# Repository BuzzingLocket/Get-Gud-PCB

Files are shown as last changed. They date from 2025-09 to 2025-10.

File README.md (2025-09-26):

# Get-Gud-PCB
Getting good at PCB
Objectives: Design a PCB with an RP2040 which includes ICs to read 9-axis of sensor data (yaw, pitch, roll, acceleration, gyro, etc)m barometric pressure and temperature.

Design requirements:
- USB-C must be included. Pay attention to VBUS as that’s your power input
- RP2040
- 9-axis measurement
- Pressure sensing
- Temperature sensing
- LCSC/JLC part # included for all symbols used (i.e C2040)
- Bonus points for readable schematics and compact layout!!!!

Using a ICM 20948 IC for 9-axis detection

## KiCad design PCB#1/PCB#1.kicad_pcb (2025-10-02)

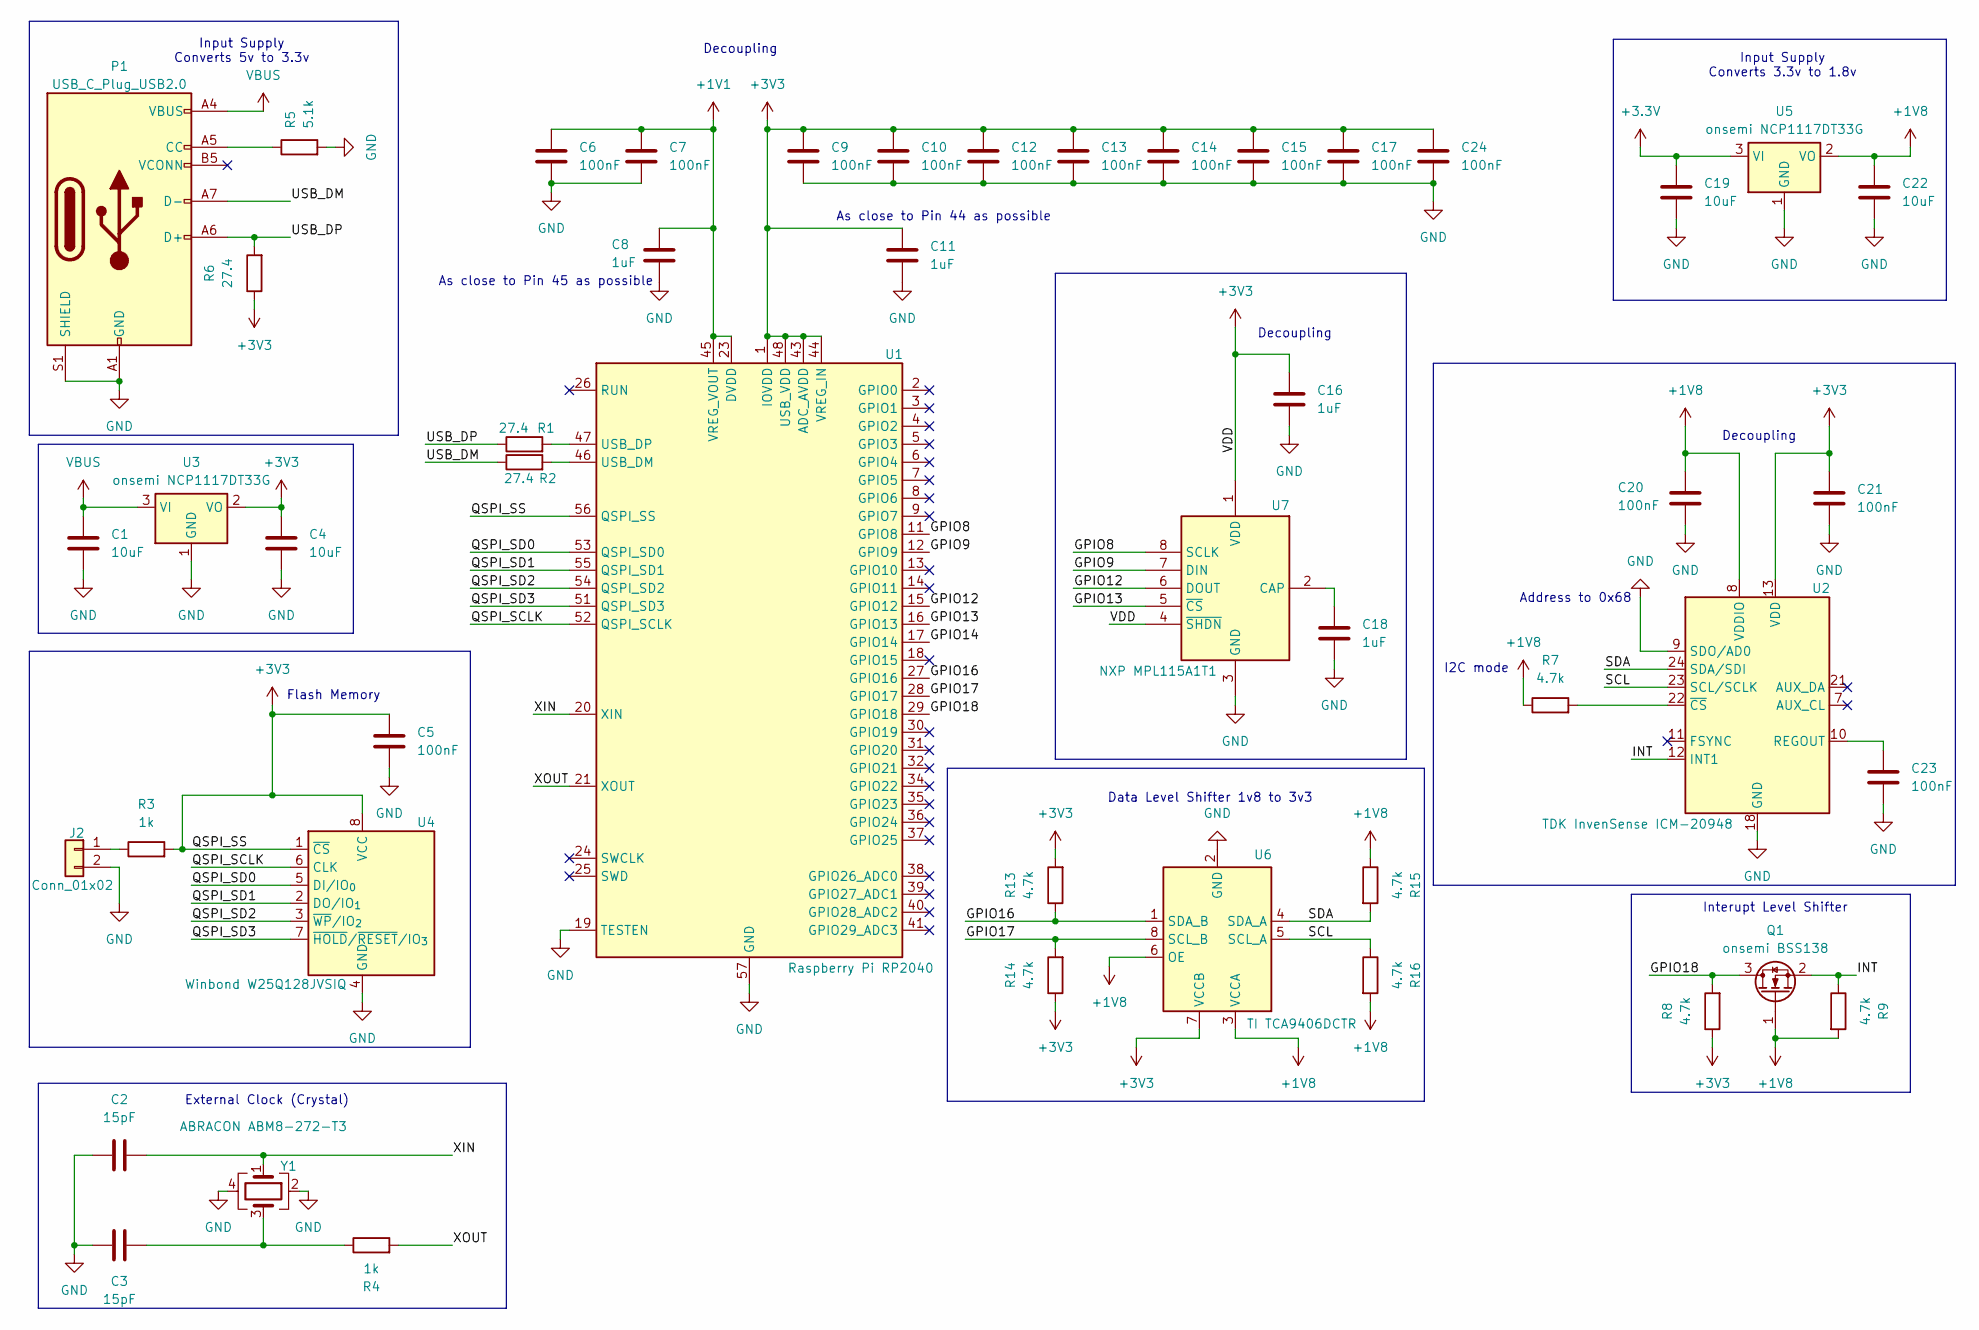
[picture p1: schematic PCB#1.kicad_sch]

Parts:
C1, C4, C19, C22: 10uF; C_0603_1608Metric
C2, C3: 15pF; C_0603_1608Metric
C5, C6, C7, C9, C10, C12, C13, C14, C15, C17, C20, C21, C23, C24: 100nF; C_0603_1608Metric
C8, C11, C16, C18: 1uF; C_0603_1608Metric
J2: Conn_01x02; PinHeader_1x02_P2.54mm_Vertical
P1: USB_C_Plug_USB2.0; USB_C_Receptacle_HRO_TYPE-C-31-M-12
Q1: onsemi BSS138; SOT-23
R1, R2, R6: 27.4; R_0603_1608Metric
R3, R4: 1k; R_0603_1608Metric
R5: 5.1k; R_0603_1608Metric
R7, R8, R9, R13, R14, R15, R16: 4.7k; R_0603_1608Metric
U1: Raspberry Pi RP2040; QFN-56-1EP_7x7mm_P0.4mm_EP3.2x3.2mm
U2: TDK InvenSense ICM-20948; InvenSense_QFN-24_3x3mm_P0.4mm
U3, U5: onsemi NCP1117DT33G; SOT-223-3_TabPin2
U4: Winbond W25Q128JVSIQ; SOIC-8_5.3x5.3mm_P1.27mm
U6: TI TCA9406DCTR; VSSOP-8_3x3mm_P0.65mm
U7: NXP MPL115A1T1; NXP_LGA-8_3x5mm_P1.25mm_H1.2mm
Y1: ABRACON ABM8-272-T3; Crystal_SMD_Abracon_ABM8G-4Pin_3.2x2.5mm

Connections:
+1V1: C6.1, C7.1, C8.1, U1.23 (DVDD), U1.45 (VREG_VOUT), U1.50 (DVDD)
+1V8: C20.1, C22.1, Q1.1 (G), R7.1, R9.2, R15.1, R16.2, U2.8 (VDDIO), U5.2 (VO), U6.3 (VCCA), U6.6 (OE)
+3.3V: C19.1, U5.3 (VI)
+3V3: C4.1, C5.1, C9.1, C10.1, C11.1, C12.1, C13.1, C14.1, C15.1, C16.1, C17.1, C21.1, C24.1, R3.2, R6.1, R8.1, R13.2, R14.1, U1.1 (IOVDD), U1.10 (IOVDD), U1.22 (IOVDD), U1.33 (IOVDD), U1.42 (IOVDD), U1.43 (ADC_AVDD), U1.44 (VREG_IN), U1.48 (USB_VDD), U1.49 (IOVDD), U1.56 (QSPI_SS), U2.13 (VDD), U3.2 (VO), U4.1 (~CS), U4.8 (VCC), U6.7 (VCCB), U7.1 (VDD), U7.4 (~SHDN)
/GPIO8: U1.11 (GPIO8), U7.8 (SCLK)
/GPIO9: U1.12 (GPIO9), U7.7 (DIN)
/GPIO12: U1.15 (GPIO12), U7.6 (DOUT)
/GPIO13: U1.16 (GPIO13), U7.5 (~CS)
/GPIO14: U1.17 (GPIO14)
/GPIO16: R13.1, U1.27 (GPIO16), U6.1 (SDA_B)
/GPIO17: R14.2, U1.28 (GPIO17), U6.8 (SCL_B)
/GPIO18: Q1.3 (D), R8.2, U1.29 (GPIO18)
/INT: Q1.2 (S), R9.1, U2.12 (INT1)
/QSPI_SCLK: U1.52 (QSPI_SCLK), U4.6 (CLK)
/QSPI_SD0: U1.53 (QSPI_SD0), U4.5 (DI/IO_{0})
/QSPI_SD1: U1.55 (QSPI_SD1), U4.2 (DO/IO_{1})
/QSPI_SD2: U1.54 (QSPI_SD2), U4.3 (~WP/IO_{2})
/QSPI_SD3: U1.51 (QSPI_SD3), U4.7 (~HOLD/~RESET/IO_{3})
/SCL: R16.1, U2.23 (SCL/SCLK), U6.5 (SCL_A)
/SDA: R15.2, U2.24 (SDA/SDI), U6.4 (SDA_A)
/USB_DM: P1.A7 (D-), R2.1
/USB_DP: P1.A6 (D+), R1.1, R6.2
/XIN: C2.1, U1.20 (XIN), Y1.1
/XOUT: R4.2, U1.21 (XOUT)
GND: C1.2, C2.2, C3.2, C4.2, C5.2, C6.2, C7.2, C8.2, C9.2, C10.2, C11.2, C12.2, C13.2, C14.2, C15.2, C16.2, C17.2, C18.2, C19.2, C20.2, C21.2, C22.2, C23.2, C24.2, J2.2, P1.A1 (GND), P1.A12 (GND), P1.B1 (GND), P1.B12 (GND), P1.S1 (SHIELD), R5.2, U1.19 (TESTEN), U1.57 (GND), U2.9 (SDO/AD0), U2.18 (GND), U2.20 (GND), U3.1 (GND), U4.4 (GND), U5.1 (GND), U6.2 (GND), U7.3 (GND), Y1.2, Y1.4
unnamed: C3.1, R4.1, Y1.3
unnamed: J2.1, R3.1
unnamed: P1.A5 (CC), R5.1
unnamed: R2.2, U1.46 (USB_DM)
unnamed: R1.2, U1.47 (USB_DP)
unnamed: C23.1, U2.10 (REGOUT)
unnamed: R7.2, U2.22 (~CS)
unnamed: C18.1, U7.2 (CAP)
VBUS: C1.1, P1.A4 (VBUS), P1.A9 (VBUS), P1.B4 (VBUS), P1.B9 (VBUS), U3.3 (VI)

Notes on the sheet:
Decoupling
External Clock (Crystal)
Input Supply Converts 3.3v to 1.8v
As close to Pin 45 as possible
Data Level Shifter 1v8 to 3v3
I2C mode
Address to 0x68
Interupt Level Shifter
Flash Memory
As close to Pin 44 as possible
Input Supply Converts 5v to 3.3v

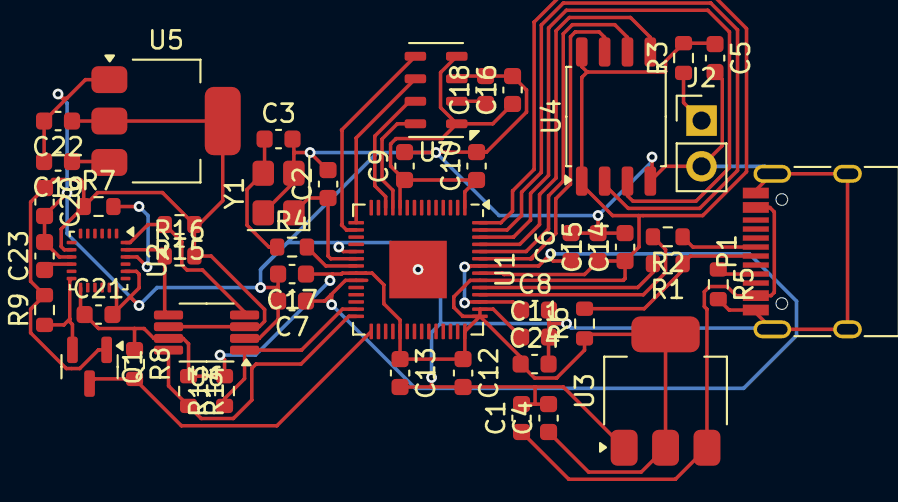
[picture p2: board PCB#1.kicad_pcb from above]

Board: 2 copper layers, 48 parts (0 on the bottom side), 33 nets.
